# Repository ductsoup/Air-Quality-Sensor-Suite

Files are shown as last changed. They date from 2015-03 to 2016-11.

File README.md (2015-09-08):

#Air Quality Sensor Suite
An air quality sensor suite based on Open Source Hardware with Modbus TCP communications for interfacing with commercial SCADA and building automation solutions.

##Overview
This suite is designed to measure temperature, humidity (DHT22), particulate dust (PPD42NS or SM-PWM-01A) and the presence of fuel gases (MQ-2).

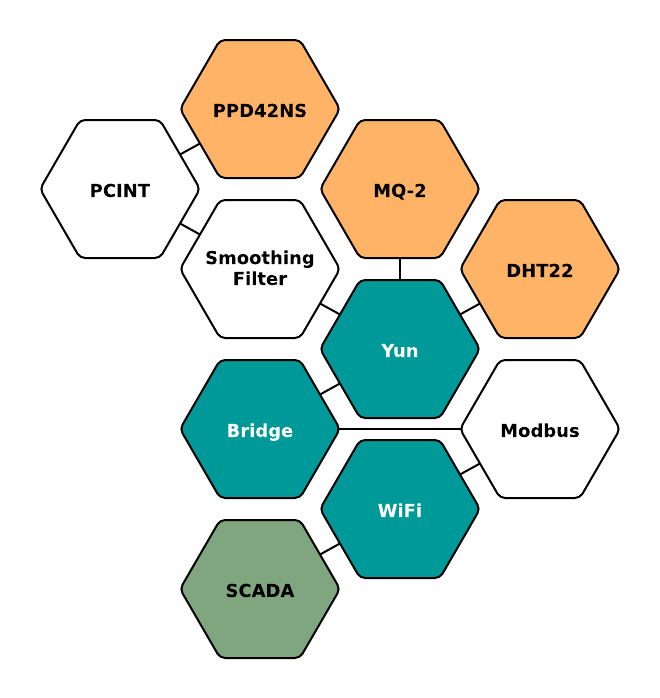
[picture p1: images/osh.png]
AQSS Overview


##Design Notes
At low concentrations it can be difficult to obtain a stable and reliable reading from the PPD42NS. To moderate that problem the Arduino sketch uses interrupt pins rather than `pulseIn(pin, LOW);` which can cause blocking. It also uses an adjustable smoothing filter technique commonly used with analog PLC inputs. Together these greatly improve the sensitivity and reliability of the particulate dust data.

The design incorporates a version of [Yun-ModbusTK-Example] (https://github.com/ductsoup/Yun-ModbusTK-Example) to communicate with the SCADA solution over Modbus TCP. 

A 3D printed enclosure design is available at [Thingiverse] (http://www.thingiverse.com/thing:1002168).

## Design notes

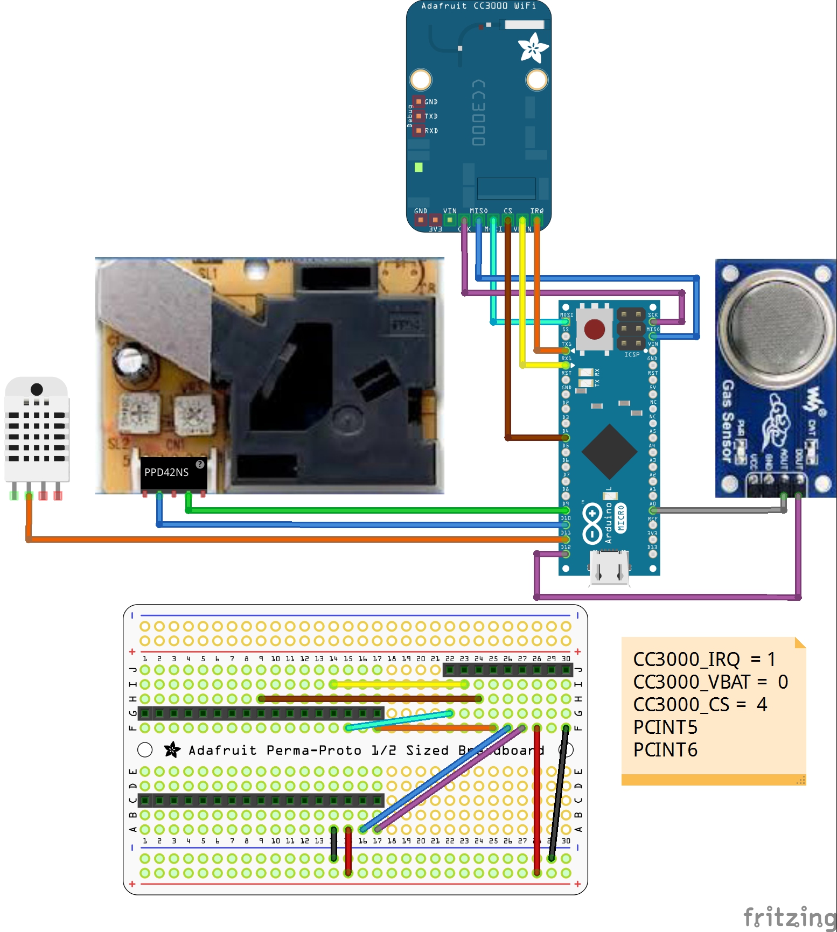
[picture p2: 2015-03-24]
hardware/iss_air3_bb.jpg

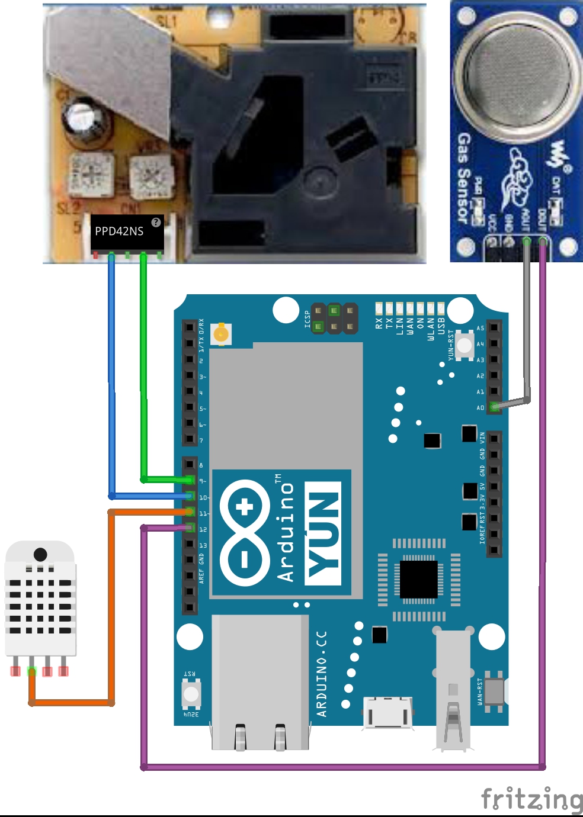
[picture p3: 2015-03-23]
hardware/iss_air4_bb.jpg

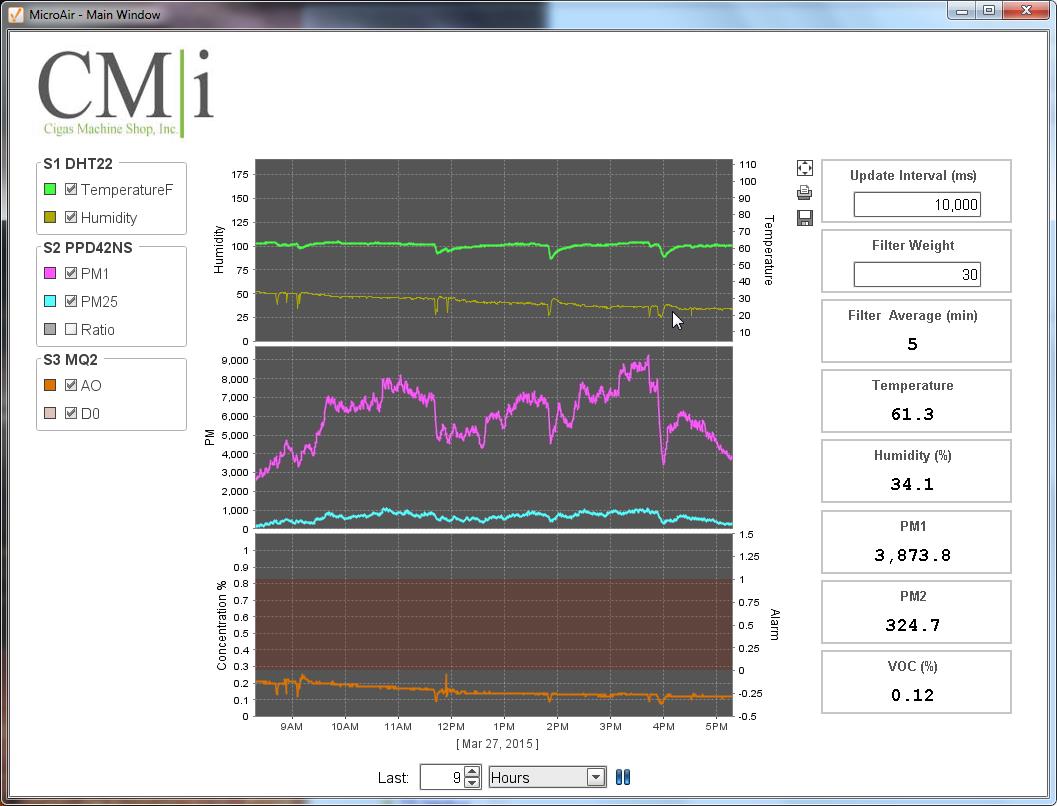
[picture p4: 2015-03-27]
images/ScreenShot001.jpg

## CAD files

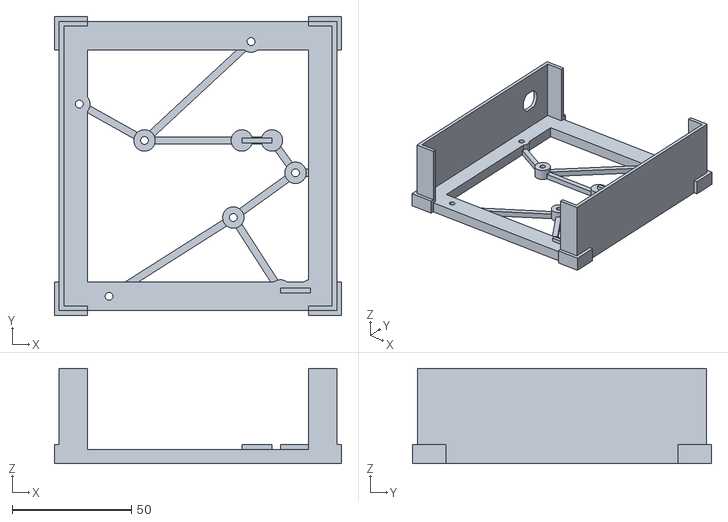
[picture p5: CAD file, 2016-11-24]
enclosure/case53_bottom.stl
120.4 x 125.3 x 40.0

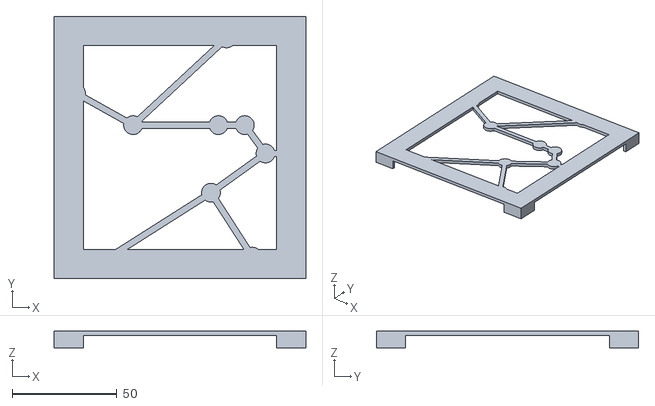
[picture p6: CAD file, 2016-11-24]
enclosure/case53_top.stl
120.4 x 125.3 x 8.00

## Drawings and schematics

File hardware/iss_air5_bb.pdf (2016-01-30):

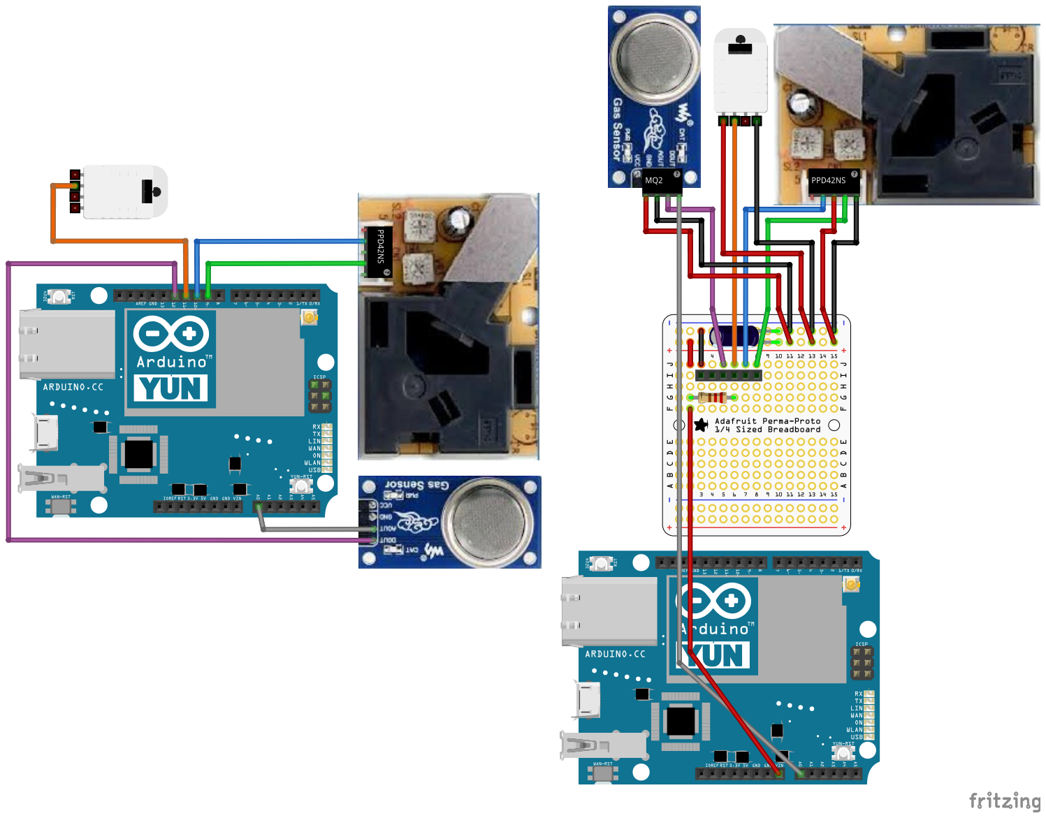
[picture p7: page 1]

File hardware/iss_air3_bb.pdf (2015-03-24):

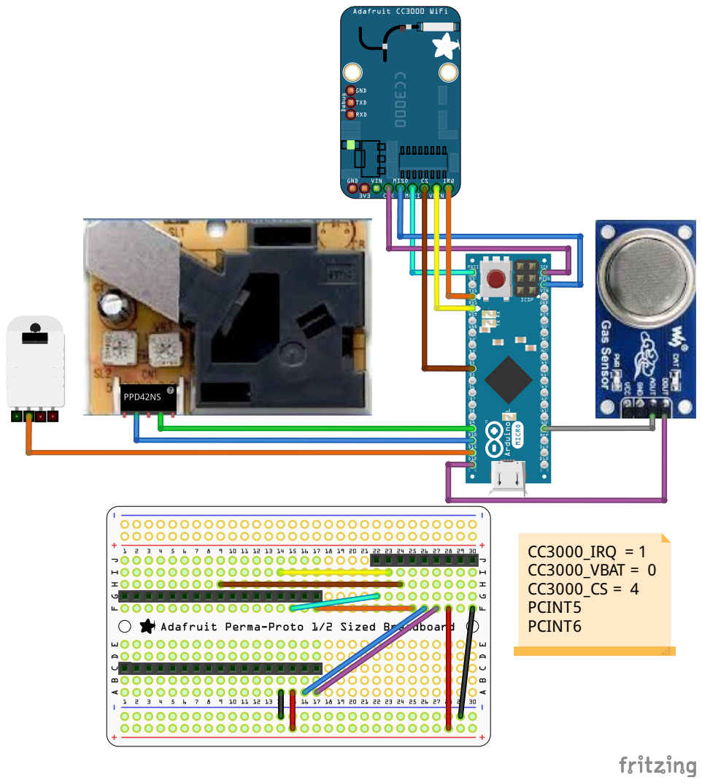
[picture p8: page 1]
CC3000_IRQ = 1 CC3000_VBAT = 0 CC3000_CS = 4 PCINT5 PCINT6

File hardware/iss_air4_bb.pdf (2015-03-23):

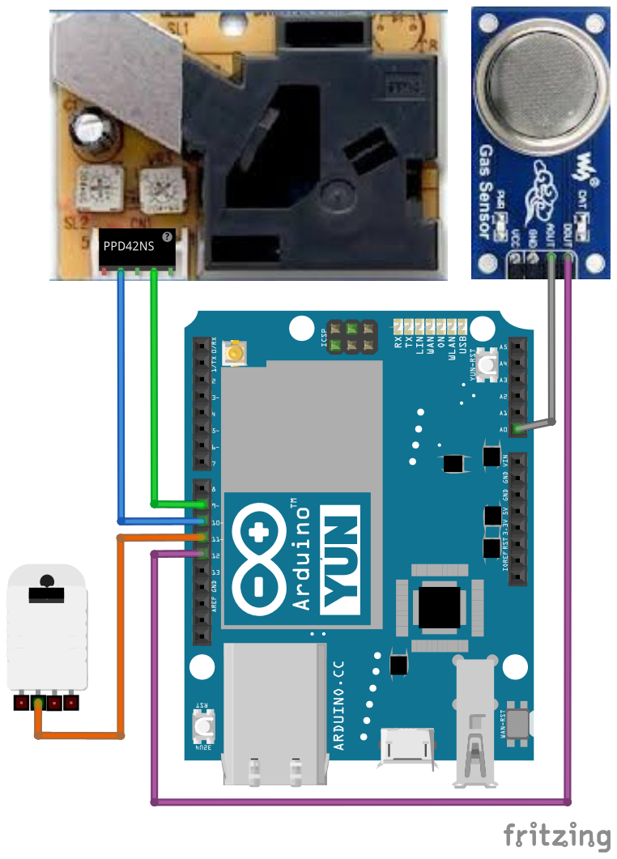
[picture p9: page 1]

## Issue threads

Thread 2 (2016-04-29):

Sensor performance

michaelshmitty, 2016-04-29:
Hi Craig,

I couldn't find a way to message you privately. I wonder if Github even has this ability?

Anyways, we're working on a open source community project where hobbyists can build their own particulates sensor to raise awareness for the health issues surrounding small dust particles.
I learned a lot from your code, thanks for publishing this. I like the idea of using interrupts in particular.

How was your experience with these sensors compared to expensive (hundreds of dollars and above), professional devices? Is the data useful or did you find them to be inadequate for any real situations?

Cheers!

Michael

ductsoup, 2016-04-30:
Michael,

Glad to help. Real world tested, think this can work for what you're doing.

I designed these to replace our failing commercial dust sensors and to give our building automation a better sense of what it feels (and smells) like to be working on the shop floor. Ours is a heavy industrial environment, we've got four of these installed and haven't had any problems at all aside from the occasional knucklehead unplugging them to poach a 120VAC outlet now and then. Honestly, I never expected the original prototype to last more than a week or two. When it didn't fail, we rolled them out in other areas.

Near as I can tell the sensor technology was developed in China where air quality is an ongoing concern. The documentation doesn't translate well but if you think through the missing and wrong words it's clear they've put a lot of thought into the design. The sensitivity and dynamic range is quite remarkable. Almost too much so.

Expect to have to log a bunch of data, understand your baseline then maybe tune the filter and sample time constants for your application to get a meaningful result. Any free IoT platform (adafruit.io, carriots/freeboard.io, etc.) can easily take the place of the commercial SCADA solution we use to help you do that.

Closed 2016-04-30.

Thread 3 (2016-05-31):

Python Script Calling problem

mhrbsl, 2016-05-31:
Hello friend.

I am using dragino Yun Shield with Arduino Mega2560. I made a project which is related with dht22 sensors. In this project, I read the values of sensors and send them to google spreadsheets. And now I want to read this values from OPC server. I have been trying to run your example codes about 1 week and I couldnt get any result.

I am newbie at python coding. I noticed that I couldnt call python script from arduino side. When I try manually open the "modbus_tcp_slave.py" on putty, I get an error message. Could you please help me about this problem ?

ductsoup, 2016-05-31:
Hi,

They python code was fully tested on an Arduino Yun, there could be some changes necessary for the shield you're using. Best to start by confirming the bridge example sketches work correctly. If you're still stuck maybe support at Dragino can help. Good luck.

Closed 2016-05-31.

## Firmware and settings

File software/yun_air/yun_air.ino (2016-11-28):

#define DEBUG
#ifdef DEBUG
#include <Console.h>
#define emit(s) Console.print(s);
#define emitln(s) Console.println(s);
#endif
//
//  Air Quality Sensor Suite
//

//
// Bridge and Modbus functions
//
#include <Bridge.h>
Process p;
// write a float to the bridge
void setFloat(char *a, float v) {
  Bridge.put(a, String(v));
#ifdef DEBUG
  emit("PUT "); emit(a); emit(":"); emitln(v);
#endif
}
// read a float from the bridge
#define BUF_SIZE 128
char buf[BUF_SIZE];
float getFloat(char *a) {
  Bridge.get(a, buf, BUF_SIZE);
#ifdef DEBUG
  emit("GET "); emit(a); emit(":"); emitln(buf);
#endif  
  return atof(buf);
}
uint32_t getLong(char *a) {
  Bridge.get(a, buf, BUF_SIZE);
#ifdef DEBUG
  emit("GET "); emit(a); emit(":"); emitln(buf);
#endif
  return atoi(buf);
}

//
// Modbus register map
//
// modpoll -m tcp -0 -c7 -t 4:float -r 40001 [ip_addr]
// modpoll -m tcp -0 -c3 -t 4:float -r 40101 [ip_addr]
//
#define RO_START "40001" // ro block
#define RO_LENGTH "7"
#define S0_CurrentMillis         "40001"
#define S1_TemperatureF          "40003"
#define S1_Humidity              "40005"
#define S2_ConcentrationPM10     "40007"
#define S2_ConcentrationPM25     "40009"
#define S3_Concentration         "40011"
#define S3_Alarm                 "40013"

#define RW_START "40101" // rw block
#define RW_LENGTH "4"
#define S1_UpdateInterval        "40101"
#define S2_UpdateInterval        "40103"
#define S2_FilterWeight          "40105"
#define S3_UpdateInterval        "40107"

//
// S1 Adafruit DHT22
// https://learn.adafruit.com/dht/connecting-to-a-dhtxx-sensor
//
#include "DHT.h"
#define S1_Pin 11
#define S1_Type DHT22
DHT dht(S1_Pin, S1_Type);

//
// S2 - Shinyei Model PPD42NS Particle Sensor
// http://www.sca-shinyei.com/pdf/PPD42NS.pdf
// SW-PWM-01A
// http://www.mouser.com/pdfdocs/AAS920643ATelaireDustSensor081414web.PDF
// http://www.digikey.com/Web%20Export/Supplier%20Content/amphenol-advanced-sensors-45/pdf/amphenol-advanced-smart-sensor.pdf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
//
#define S2_P1_Pin 10
#define S2_P2_Pin  9

//
// S3 - MQ-2
//
#define MQ2_D  12
#define MQ2_A  A0

// interrupt and timer storage
unsigned long S0StartTime = 0, S1StartTime = 0, S2StartTime = 0, S3StartTime = 0;
int state09 = HIGH, state10 = HIGH;
unsigned long start09, start10;
volatile unsigned long lpo09, lpo10;

void setup(void)
{
  // Start the bridge
  Bridge.begin();
#ifdef DEBUG
  Console.begin();
  delay(2000);
  emitln("Hello world!");
#endif  
  pinMode(13, OUTPUT);
  digitalWrite(13, LOW);

  // Initialize S1
  dht.begin();
  setFloat(S1_UpdateInterval, 10000.0);

  // Initialize S2
  pinMode(S2_P1_Pin, INPUT);
  pinMode(S2_P2_Pin, INPUT);
  // pin change interrupt
  PCMSK0 |= bit (PCINT5);  // want pin  9
  PCMSK0 |= bit (PCINT6);  // want pin 10
  PCIFR  |= bit (PCIF0);   // clear any outstanding interrupts
  PCICR  |= bit (PCIE0);   // enable pin change interrupts for D8 to D13
  setFloat(S2_UpdateInterval, 10000.0);
  setFloat(S2_FilterWeight, 30.0);

  // Initialize S3
  pinMode(MQ2_A, INPUT);
  pinMode(MQ2_D, INPUT);
  setFloat(S3_UpdateInterval, 10000.0);

  // Start the modbus server script
  // in case a previous connection needs to timeout
  
  // kill -9 $(ps | grep "modbus" | awk '{ print $1 }')
  // kill -9 $( pgrep -f "python /mnt/sd/modbus_tcp_slave.py")
//  p.runShellCommand("kill -9 $( pgrep -f \"python /mnt/sd/modbus_tcp_slave.py\")");  
//  while (p.available() > 0);
  delay(125000);

  p.begin("python");
  p.addParameter("/mnt/sda1/modbus_tcp_slave.py"); // modbus float holding registers
  p.addParameter(RO_START);                      // read only start address
  p.addParameter(RO_LENGTH);                     // read only number of holding registers
  p.addParameter(RW_START);                      // read/write start address (optional)
  p.addParameter(RW_LENGTH);                     // read/write number of holding registers (optional)
  p.runAsynchronously();
  delay(5000);
  // 
  lpo09 = lpo10 = 0;
}

// optional limiter for S2
unsigned long limit(unsigned long x) {
  //  return (x < 10000ul || x > 90000ul) ? 0 : x;
  return x;
}
// interrupt service routine
ISR (PCINT0_vect) {
  unsigned long us = micros();
  if (state09 != digitalRead(S2_P2_Pin))
    if ((state09 = digitalRead(S2_P2_Pin)) == LOW)
      start09 = us;
    else
      lpo09 += limit(us - start09);
  if (state10 != digitalRead(S2_P1_Pin))
    if ((state10 = digitalRead(S2_P1_Pin)) == LOW)
      start10 = us;
    else
      lpo10 += limit(us - start10);
}

//
// poll the sensors and update the bridge
//
void loop(void)
{
  unsigned long curMillis = millis();
  float x, y;

  // S0 - suite
  if (curMillis - S0StartTime > 1000) {
    setFloat(S0_CurrentMillis, curMillis);
    S0StartTime = curMillis;
  }

  // S1 - temperature and humidity
  if (curMillis - S1StartTime > getLong(S1_UpdateInterval)) {
    digitalWrite(13, HIGH);
    setFloat(S1_TemperatureF, dht.readTemperature(true) - 4.0); // correction for mounting too close to MQ-2
    setFloat(S1_Humidity, dht.readHumidity());

    S1StartTime = curMillis;
    digitalWrite(13, LOW);
  }

  // S2 - particulate dust
  if (curMillis - S2StartTime > getLong(S2_UpdateInterval)) {
    digitalWrite(13, HIGH);
    x = 0.1 * float(lpo10) / getFloat(S2_UpdateInterval);
    y = 1.1 * x * x * x  - 3.8 * x * x + 520 * x; // + 0.62;
    setFloat(S2_ConcentrationPM10, (y + getFloat(S2_ConcentrationPM10) * (getFloat(S2_FilterWeight) - 1.0)) / getFloat(S2_FilterWeight));
    lpo10 = 0;

    x = 0.1 * float(lpo09) / getFloat(S2_UpdateInterval);
    y = 1.1 * x * x * x  - 3.8 * x * x + 520 * x; // + 0.62;
    setFloat(S2_ConcentrationPM25, (y + getFloat(S2_ConcentrationPM25) * (getFloat(S2_FilterWeight) - 1.0)) / getFloat(S2_FilterWeight));

    lpo09 = 0;
    S2StartTime = curMillis;
    digitalWrite(13, LOW);
  }

  // S3 - volatile organic compounds
  if (curMillis - S3StartTime > getLong(S3_UpdateInterval)) {
    digitalWrite(13, HIGH);
    setFloat(S3_Concentration, (5.0 / 4.0) * (float(analogRead(MQ2_A)) / 1024.0));
    setFloat(S3_Alarm, float(digitalRead(MQ2_D)));
    S3StartTime = curMillis;
    digitalWrite(13, LOW);
  }
}

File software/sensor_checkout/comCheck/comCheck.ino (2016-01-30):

// Example testing sketch for communications
// Written by Ductsoup, public domain
// Updated to use Yun console
#define CONSOLE
#ifdef CONSOLE
#include <Console.h>
#define emit(s) Console.print(s);
#define emitln(s) Console.println(s);
#else
#define emit(s) Serial.print(s);
#define emitln(s) Serial.println(s);
#endif

void setup() {
#ifdef CONSOLE
  Bridge.begin();
  Console.begin();
  while (!Console);
#else
  Serial.begin(115200);
#endif
  delay(2000);
  emitln("Communications check!");
}

void loop() {
  emit(".");
  delay(2000);
}

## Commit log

2015-03-24 Added hardware details
    Added sensor details, sensor checkout sketches and prior Arduino Micro
    circuit design
    [iss_air3.fzz]
2016-01-30 added com check utility
    [iss_air5.fzz]
2016-11-24 Added enclosure
    [case53_bottom.stl, case53_top.stl]
2016-11-28 updated SD mount point
